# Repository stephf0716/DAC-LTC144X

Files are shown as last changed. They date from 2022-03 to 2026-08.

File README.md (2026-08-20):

# DAC-LTC144X

A small KiCad breakout board and an Arduino driver for the **Linear Technology
LTC1446 / LTC1446L** — a dual 12-bit rail-to-rail DAC with an internal
reference and a 3-wire SPI interface in an 8-pin package.

<!-- Board render and schematic images go in docs/ and get embedded here. -->

## The part

| | LTC1446 | LTC1446L |
|---|---|---|
| Supply | 4.5V – 5.5V | 2.7V – 5.5V |
| Full-scale output | 4.095V (1mV per LSB) | 2.5V |
| Resolution | 12 bits, 2 channels | 12 bits, 2 channels |
| Interface | 3-wire SPI, 24-bit word | 3-wire SPI, 24-bit word |
| Settling time | 14µs to ±0.5 LSB | 14µs to ±0.5 LSB |

Both channels are written in a single 24-bit transfer: the first 12 bits set
DAC A, the second 12 set DAC B. Data is latched on the **rising** edge of CLK
(SPI mode 0, MSB first), and the outputs update when CS/LD returns high. The
DAC has a power-on reset that clears both channels to 0V.

## The board

Two-layer, 18 × 22 mm, through-hole headers, designed in KiCad 6.

| Ref | Value | Purpose |
|---|---|---|
| U1 | LTC1446 | Dual 12-bit DAC, SO-8 |
| R1 | 10k | Pull-up on CS/LD to VCC |
| C1 | 0.1µF | VCC bypass |
| J1 | 1x5 header | Control in — CLK, D_IN, CS, VCC, GND |
| J2 | 1x2 header | Analog out — Vout A, Vout B |

Open `LTC1446-BRD.kicad_pro` in KiCad 6 or newer.

### Wiring

| J1 pin | Signal | Arduino (Uno) |
|---|---|---|
| 1 | CLK | 13 (SCK) |
| 2 | D_IN | 11 (MOSI) |
| 3 | CS | 10 (or any digital pin) |
| 4 | VCC | 5V |
| 5 | GND | GND |

The DAC's D_OUT pin is brought to U1 only; it exists so multiple LTC1446s can
be daisy-chained, and is left unconnected on this board.

## The Arduino library

Copy this repository into your Arduino `libraries/` folder, or clone it there:

```bash
git clone https://github.com/stephf0716/DAC-LTC144X ~/Documents/Arduino/libraries/LTC1446
```

```cpp
#include <LTC1446.h>

LTC1446 dac(10);  // CS/LD wired to pin 10

void setup() {
  dac.begin();
  dac.setVoltage(2048, 0);  // A to mid-scale (~2.048V), B to 0V
}

void loop() {}
```

### API

- `LTC1446(uint8_t csPin)` — construct with the pin wired to CS/LD.
- `begin()` — configures the CS pin and starts SPI.
- `setVoltage(uint16_t voutA, uint16_t voutB)` — writes both channels in one
  transfer. Codes run `0` to `LTC1446_MAX_CODE` (4095) and are clamped, since
  a value wider than 12 bits would overflow into the other channel.

See [examples/BasicSweep](examples/BasicSweep/BasicSweep.ino) for a full sketch
that ramps both channels.

## Repository layout

```
src/                    Arduino library sources
examples/BasicSweep/    example sketch
datasheets/             LTC1446 datasheet
LTC1446-BRD.*           KiCad 6 project, schematic, and PCB layout
```

## License

MIT — see [LICENSE](LICENSE). The bundled datasheet is the property of Linear
Technology / Analog Devices and is included for convenience only.

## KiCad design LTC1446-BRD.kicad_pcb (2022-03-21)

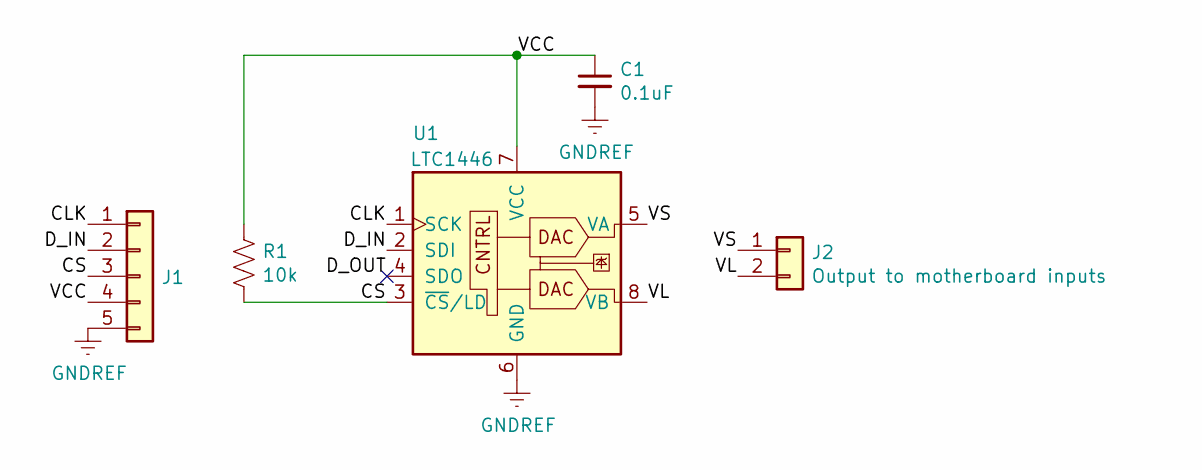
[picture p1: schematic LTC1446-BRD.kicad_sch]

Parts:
C1: 0.1uF; C_0805_2012Metric_Pad1.15x1.40mm_HandSolder
J1: Conn_01x05; PinSocket_1x05_P2.54mm_Vertical
J2: Output to motherboard inputs; PinSocket_1x02_P2.54mm_Vertical
R1: 10k; R_Axial_DIN0207_L6.3mm_D2.5mm_P10.16mm_Horizontal
U1: LTC1446; DIP-8_W7.62mm_Socket

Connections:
/CLK: J1.1, U1.1 (SCK)
/CS: J1.3, R1.2, U1.3 (~CS/LD)
/D_IN: J1.2, U1.2 (SDI)
/D_OUT: U1.4 (SDO)
/VCC: C1.1, J1.4, R1.1, U1.7 (VCC)
/VL: J2.2, U1.8 (VB)
/VS: J2.1, U1.5 (VA)
GNDREF: C1.2, J1.5, U1.6 (GND)

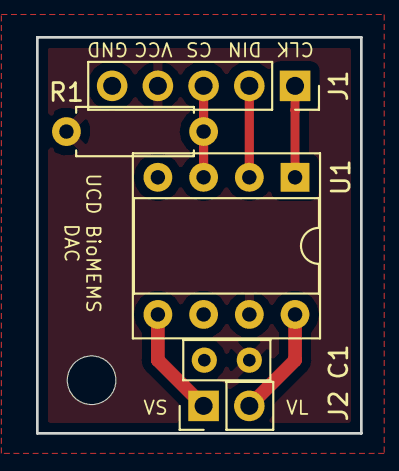
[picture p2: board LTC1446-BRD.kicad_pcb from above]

Board: 2 copper layers, 18.0 x 22.0 mm, 5 parts (0 on the bottom side), 7 nets.

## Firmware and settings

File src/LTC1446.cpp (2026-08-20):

/*
  LTC1446.cpp - Library for the LTC1446 / LTC1446L dual 12-bit SPI DAC.
  Created by Stephanie Fung, July 31, 2017.
  Released under the MIT License.
*/

#include "Arduino.h"
#include <SPI.h>

#include "LTC1446.h"

// The DAC latches D_IN on the rising edge of CLK, MSB first, so SPI mode 0.
// The datasheet specifies a 60ns minimum CLK high and low time (~8MHz
// ceiling); 4MHz leaves comfortable margin over the full temperature range.
static const SPISettings LTC1446_SPI(4000000, MSBFIRST, SPI_MODE0);

/**************************************************************************/
/*!
    @brief  Instantiates a new LTC1446 class
    @param[in]  csPin
                The pin wired to the DAC's CS/LD input.
*/
/**************************************************************************/
LTC1446::LTC1446(uint8_t csPin) {
  _cspin = csPin;
}

/**************************************************************************/
/*!
    @brief  Sets up the HW. Idles CS/LD high so the first transfer is clean.
*/
/**************************************************************************/
void LTC1446::begin() {
  pinMode(_cspin, OUTPUT);
  digitalWrite(_cspin, HIGH);
  SPI.begin();
}

/**************************************************************************/
/*!
    @brief  Sets the output voltages to a fraction of the internal vref.
            (Values can be 0..4095, and are clamped to that range: a code
            wider than 12 bits would overflow into the other channel.)
    @param[in]  voutA, voutB
                The 12-bit values representing the relationship between
                the DAC's reference voltage and each output voltage.
*/
/**************************************************************************/
void LTC1446::setVoltage( uint16_t voutA, uint16_t voutB )
{
    if (voutA > LTC1446_MAX_CODE) voutA = LTC1446_MAX_CODE;
    if (voutB > LTC1446_MAX_CODE) voutB = LTC1446_MAX_CODE;

    // pack the two 12-bit codes into the DAC's 24-bit word, A first
    uint16_t shifted_a = voutA << 4;
    byte byte_1, byte_2, byte_3;
    byte_1 = highByte(shifted_a);                       // A[11:4]
    byte_2 = lowByte(shifted_a) | highByte(voutB);      // A[3:0], B[11:8]
    byte_3 = lowByte(voutB);                            // B[7:0]

    SPI.beginTransaction(LTC1446_SPI);
    // take the CS pin low to select the chip:
    digitalWrite(_cspin, LOW);
    // send in the value via SPI:
    SPI.transfer(byte_1);
    SPI.transfer(byte_2);
    SPI.transfer(byte_3);
    // take the CS pin high to load the DACs from the shift register:
    digitalWrite(_cspin, HIGH);
    SPI.endTransaction();
}

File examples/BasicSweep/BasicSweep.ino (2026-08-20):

/*
  LTC1446 BasicSweep

  Ramps both channels of a Linear Technology LTC1446 dual 12-bit DAC:
  channel A sweeps up while channel B sweeps down.

  The LTC1446 is SPI-compatible. Data is loaded as a single 24-bit word,
  MSB first: the first 12 bits are for DAC A, the second 12 for DAC B.
  Codes run 0..4095. On the LTC1446 full scale is 4.095V (1mV per LSB);
  on the LTC1446L it is 2.5V.

  Connections to the microcontroller (LTC1446 pin numbers):
  1 - CLK    -> SCK
  2 - D_IN   -> MOSI
  3 - CS/LD  -> CS_PIN below
  4 - D_OUT  -> not connected
  5 - Vout A -> your load
  6 - GND    -> ground
  7 - Vcc    -> 5V (bypass with 0.1uF)
  8 - Vout B -> your load

  created 29 Jul 2017
  by Stephanie Fung
*/

#include <LTC1446.h>

// the pin wired to the DAC's CS/LD input:
const uint8_t CS_PIN = 10;

LTC1446 dac(CS_PIN);

void setup() {
  dac.begin();
}

void loop() {
  // walk channel A up through all 4096 levels while B walks down:
  for (uint16_t code = 0; code <= LTC1446_MAX_CODE; code++) {
    dac.setVoltage(code, LTC1446_MAX_CODE - code);
    delay(2);
  }
  // hold at the endpoints for half a second before repeating:
  delay(500);
}

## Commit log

2018-07-12 added the Arduino lib
2018-07-31 Finished LTC1446 board
2018-08-03 PCB adjustments
    * added pull-up on CS
    * added a mounting hole
    [LTC1446-BRD.kicad_pcb, LTC1446-BRD.sch]
2022-03-21 project structure update
    * deleted unused datasheet
    * updated to latest kicad version
    [LTC1446-BRD.kicad_pcb, LTC1446-BRD.kicad_sch, LTC1446-BRD.sch]
2026-08-20 Fix Arduino library, restructure to 1.5+ layout, expand README
    The library did not compile. LTC1446.cpp defined a no-arg constructor
    while the header declared LTC1446(int pin), and setVoltage() referenced
    DAC_A/DAC_B instead of its own parameters -- both hard errors. begin()
    also never set the CS pin as an output.
    - match the constructor to the header and use the real parameters
    - pinMode/idle CS high in begin()
    - clamp codes to 12 bits; a wider value overflowed the other channel
    - wrap transfers in SPI.beginTransaction with explicit SPISettings
    (4MHz, MSBFIRST, mode 0 -- the DAC latches on the rising CLK edge)
    - move sources to src/ and the sketch to examples/BasicSweep/, and add
    libra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
    [BasicSweep.ino, LTC1446.cpp]
